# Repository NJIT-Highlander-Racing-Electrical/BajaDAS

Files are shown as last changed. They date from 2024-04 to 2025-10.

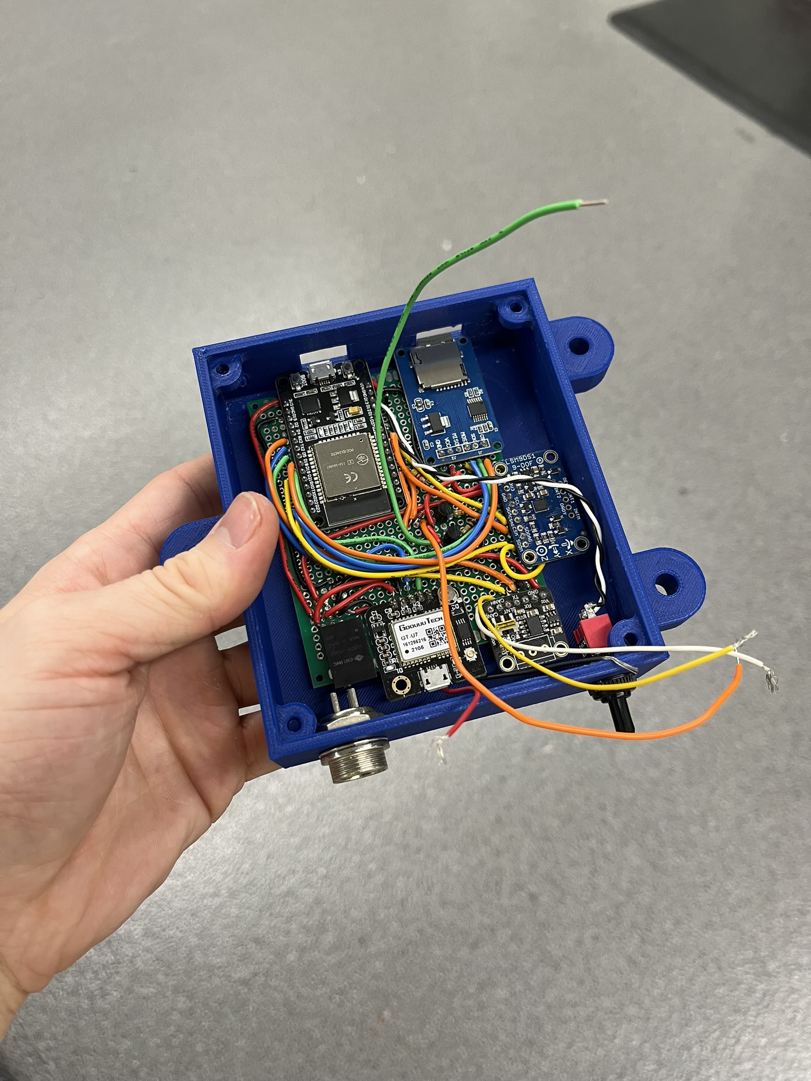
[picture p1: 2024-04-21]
Photos/IMG_1275.JPEG

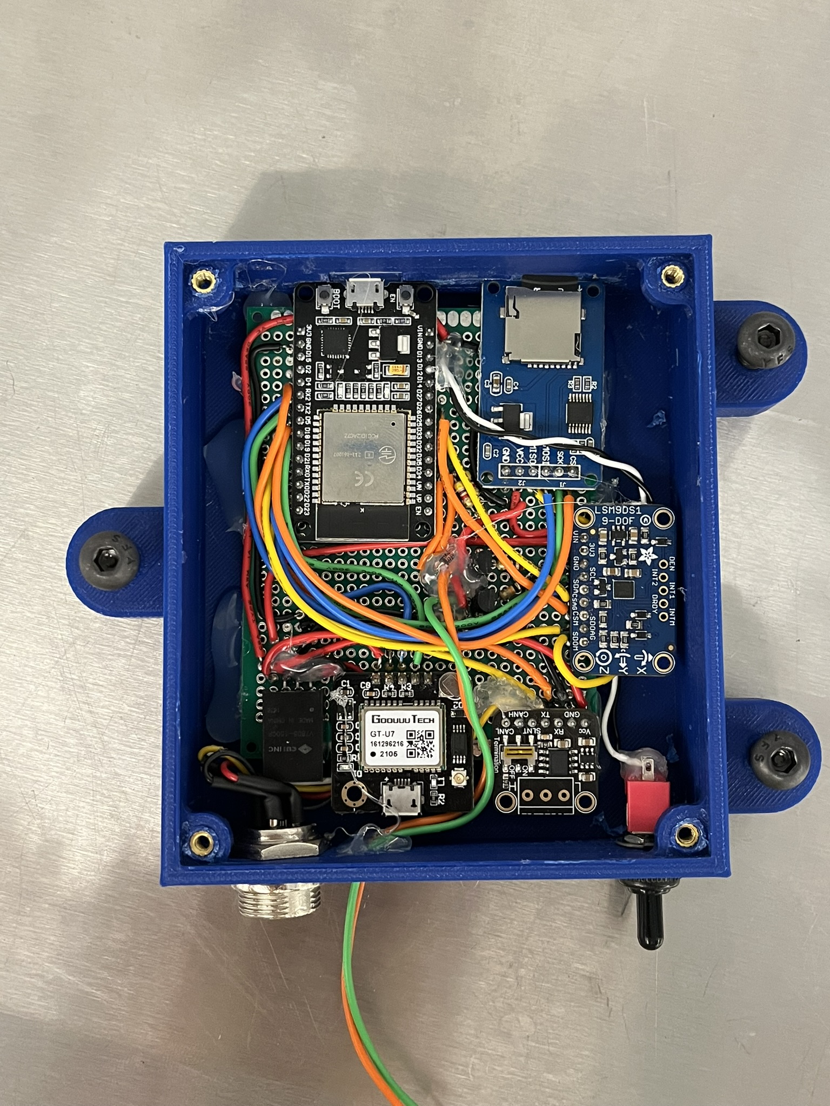
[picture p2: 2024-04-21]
Photos/IMG_1279.JPEG

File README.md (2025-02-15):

# BajaDAS: Readme and Quickstart Guide

## PlatformIO 

1. Install `Visual Studio Code`.
2. Install the `PlatformIO IDE` and `GitHub Repositories` extensions.
3. From a new window, click on `Clone Git Repository` and follow prompts to download a local copy of the code.

## Quick Start

1. Insert a formatted `MicroSD` card into the BajaDAS system.
2. Open the project folder in `Visual Studio Code`.
3. Use the `PlatformIO: Upload` button to load the code onto the microcontroller.
4. Post-race, retrieve the SD card and access the `.csv` files for analysis.

## Troubleshooting

- The main config file is `platformio.ini`.

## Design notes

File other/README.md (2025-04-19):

# BajaDAS: Data Acquisition System for Highlander Racing

BajaDAS is a data acquisition system tailored for the Highlander Racing team's vehicles. It gathers real-time telemetry data, crucial for performance analytics and diagnostics.

## 2025-2026 Changes to Make

* Incorporate this [Adafruit Panel Mount Micro SD Card Extender](https://www.google.com/aclk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) for easier use. This will require a waterproof screw on or press fit cover but will make removing the microSD far easier
     * I think we can also just place a microSD card slot for the other end of that panel mount directly to the PCB. It looks like the "reader" we use now just does some voltage regulation and level shifting, but since the ESP32 already uses 3.3V we may be OK without the additional hardware
     * Update the 3D Model and the PCB accordingly for these changes

* Include external pull-up resistors for any input pins on 34, 35, 36, or 39 since these do not have internal pullups

## Features

- **9-DOF Sensor**: Gathers acceleration, magnetic field, gyroscope, and temperature data via the `Adafruit_LSM9DS1` sensor.
- **GPS Integration**: Records GPS data, specifically latitude, longitude, fix status, and satellite count.
- **SD Card Logging**: Logs data to an SD card in CSV format.
- **Serial Logging**: Outputs sensor readings to the serial console for live monitoring.
- **CAN Bus Support**: Receives all incoming vehicle data using a TJA1051T CAN Transceiver.
- **Connection Modularity**: Screw Terminals on DAQ PCB so that additional modules can be connected to the microcontroller in the future
- **Fuel Sensor**: Integrates the fuel sensor and data storage as a part of the DAS

## Hardware Setup

- **Microcontroller**: Designed for Arduino-compatible boards with multiple hardware serial interfaces and SPI capabilities.
- **SD Card**: MicroSD card slot for data logging. Ensure it's formatted correctly.
- **Sensors**: Adafruit LSM9DS1 9-DOF sensor and a GPS module.

## GPS Information

* GPS System that tracks vehicle location (latitude and longitude) as well as reporting other information like time and date

### GPS Design Goals

* CAN-Bus integration with Adafruit Ultimate GPS module reports latitude, longitude, time, and date
* Active antenna mounted to firewall increases reception

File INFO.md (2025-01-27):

# BajaDAS: Data Acquisition System for Highlander Racing

BajaDAS is a data acquisition system tailored for the Highlander Racing team's vehicles. It gathers real-time telemetry data, crucial for performance analytics and diagnostics.

## King Andrew's Winter Break Updates

* I had some issues with the SD card where I would get the message that "The physical drive cannot work." It turned out to be a bad reader.
  
* Pins 34, 35, 36, 39 do not have internal pullups but we have buttons attahed to 34 and 35. Since buying a whole new PCB for such a minor issue is a royal PITA, I soldered two pullup resistors on the underside of the PCB on the ESP32 from 3.3V to 34 and 35

* The Ultimate GPS Module was not communicating properly with the ESP32 over Hardware Serial 2
    * Originally, I thought this was because the module was given 5V on VIN and was not operating at the proper logic level.
    * However, I found that it does work at either voltage due to the following:
        *  Adafruit says the GPS TX pin is 3.3V logic level (seemingly regardless of VIN voltage)
        *  On GPS RX, "You can use use 3.3V or 5V logic, there is a logic level shifter."
    * I was able to get communication working by reading the data directly to serial without adafruit's parsing stuff: Serial2.begin(9600, SERIAL_8N1, 16, 17);
    * It seems that the Adafruit code does not properly initialize the Serial2 port for reading data
    * The AdafruitGPSTestSketch uplaoded in this repo works to receive and parse data and is a good starting point for the full DAS program

## Important Notes + 2025 Research Topics

* It would be beneficial to add code to offset the "zero" point of the accelerometer/correct the readings. It is not mounted perfectly square on the car relative to ground. This code could also correct gyro readings based off of accelerometer orientation

* Occassionaly, numbers will get shifted or have other erroneous digits added to them in the SD logging. Maybe a buffer should be added that saves every value to that so that no values are misprinted to the log.

* Make sure that the DAS this year saves more of the GPS data. Heading, velocity, elevation, etc

* Make sure that the DAS uses the voltage divider onboard for battery level measurement
    * This will have to be calibrated manually by measuring battery voltage

* Make sure that the GPS is reporting new data at a 10Hz rate

* Make sure DAS transmits vehicle velocity to CAN Bus (for wheel speed sensors slip/skid detection)

* Also make it very easy to switch timezone offsets for GPS time (we'll be in Arizona)

## 2025-2026 Changes to Make

* Incorporate this [Adafruit Panel Mount Micro SD Card Extender](https://www.google.com/aclk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) for easier use. This will require a waterproof screw on or press fit cover but will make removing the microSD far easier
     * I think we can also just place a microSD card slot for the other end of that panel mount directly to the PCB. It looks like the "reader" we use now just does some voltage regulation and level shifting, but since the ESP32 already uses 3.3V we may be OK without the additional hardware
     * Update the 3D Model and the PCB accordingly for these changes

* Include external pull-up resistors for any input pins on 34, 35, 36, or 39 since these do not have internal pullups

## Features

- **9-DOF Sensor**: Gathers acceleration, magnetic field, gyroscope, and temperature data via the `Adafruit_LSM9DS1` sensor.
- **GPS Integration**: Records GPS data, specifically latitude, longitude, fix status, and satellite count.
- **SD Card Logging**: Logs data to an SD card in CSV format.
- **Serial Logging**: Outputs sensor readings to the serial console for live monitoring.
- **CAN Bus Support**: Receives all incoming vehicle data using a TJA1051T CAN Transceiver.
- **Connection Modularity**: Screw Terminals on DAQ PCB so that additional modules can be connected to the microcontroller in the future
- **Fuel Sensor**: Integrates the fuel sensor and data storage as a part of the DAS

## Hardware Setup

- **Microcontroller**: Designed for Arduino-compatible boards with multiple hardware serial interfaces and SPI capabilities.
- **SD Card**: MicroSD card slot for data logging. Ensure it's formatted correctly.
- **Sensors**: Adafruit LSM9DS1 9-DOF sensor and a GPS module.

## GPS Information

* GPS System that tracks vehicle location (latitude and longitude) as well as reporting other information like time and date

### GPS Design Goals

* CAN-Bus integration with Adafruit Ultimate GPS module reports latitude, longitude, time, and date
* Active antenna mounted to firewall increases reception 
  
## Fuel Sensor

* The fuel sensor is integrated into the DAS for the following reasons:
     * It is physically close to the DAS and a simple circuit with few wires
     * It does not require complex math or data processing
     * A fuel reset switch can be embedded into the DAS enclosure
     * There also needs to be a DAQ recording on/off switch
     * The SD Card on the DAS can also include a file with the last known fuel level for when the vehicle is powered back on 

## Quick Start

Note: PlatformIO is required for this project.

1. Open the project files in PlatformIO.
2. Insert a formatted MicroSD card into the BajaDAS system.
3. Use the `PlatformIO: Upload` button to load the code onto the microcontroller.
4. Use a Serial Monitor at a `115200` baud rate to view data.
5. Post-race, retrieve the SD card and access the `.csv` files for analysis.

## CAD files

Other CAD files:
3D Models/DAQ Housing.step
other/3D Models/2024-2025 DAS Enclosure v45.step
2023-2024 Archive/3D Models/DAQ Housing.step

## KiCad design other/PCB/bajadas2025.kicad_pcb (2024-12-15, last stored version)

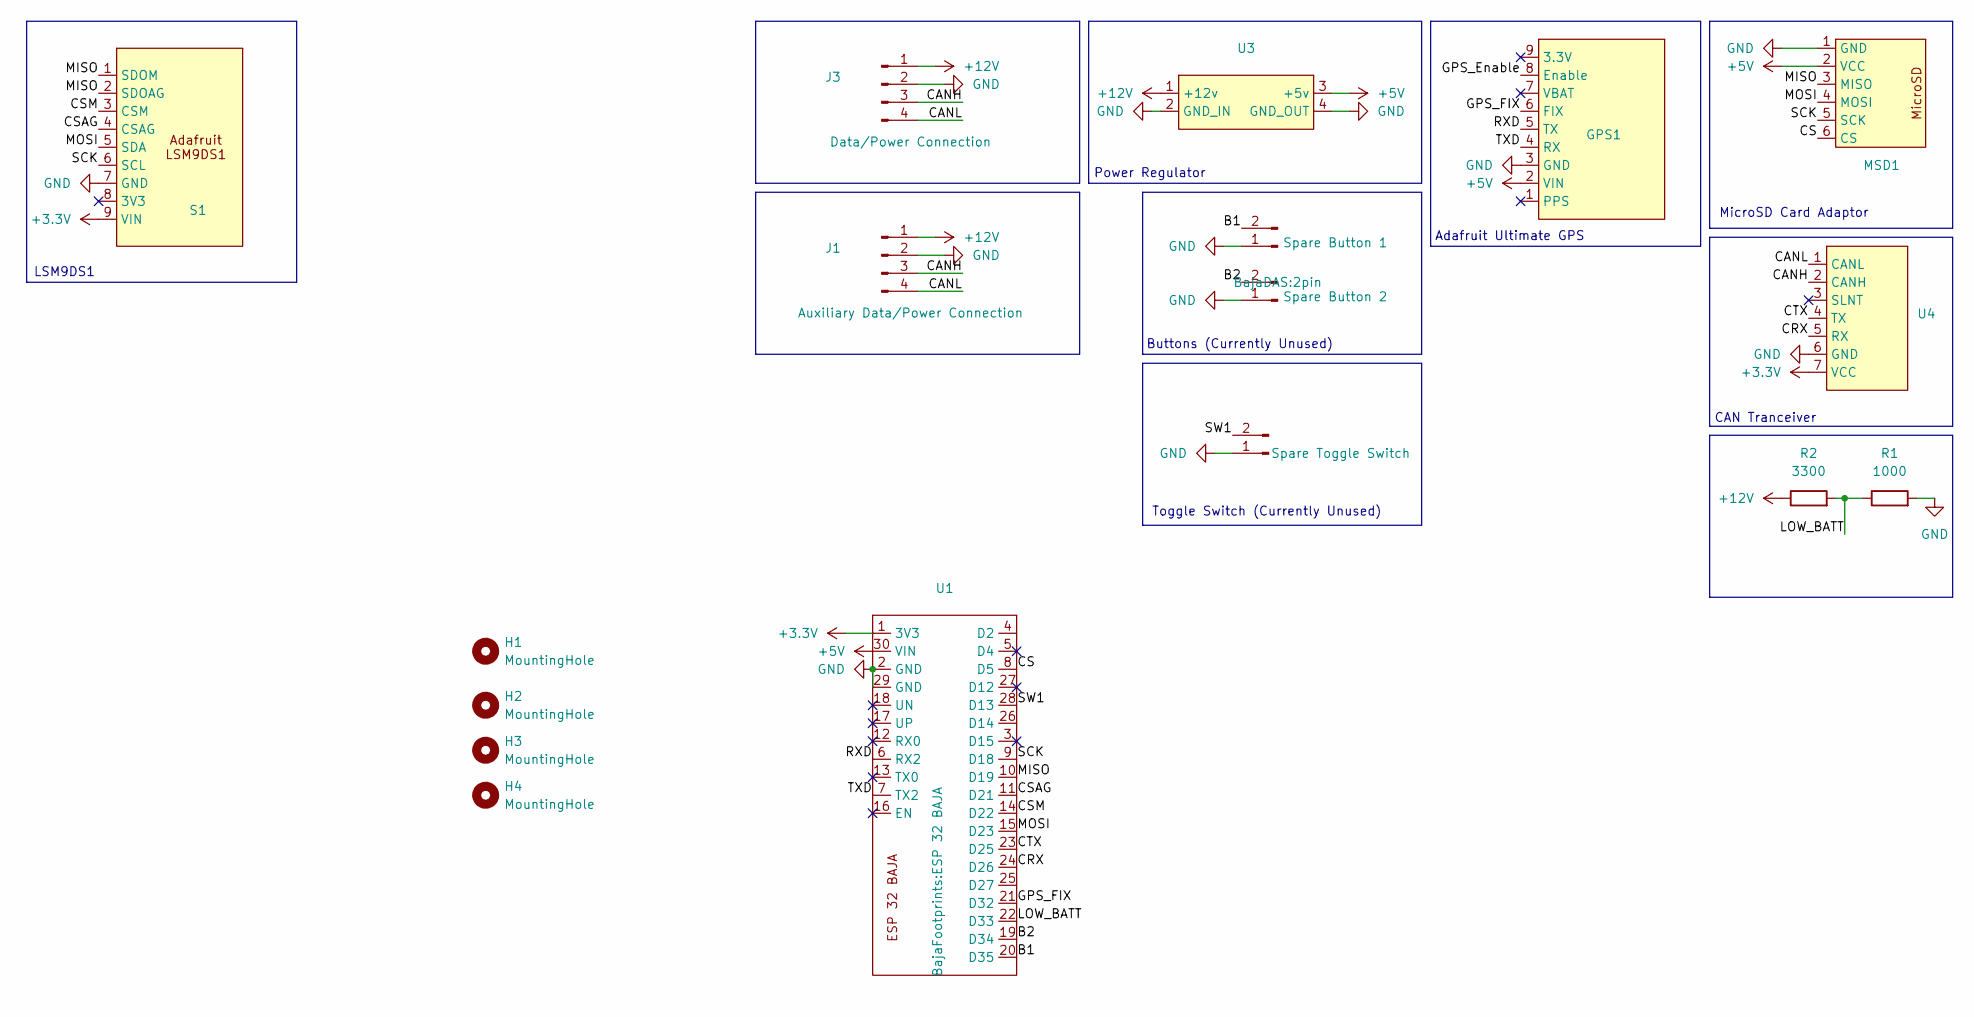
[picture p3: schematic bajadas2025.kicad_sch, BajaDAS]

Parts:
GPS1: Adafruit Ultimate GPS v1
H1, H2, H3, H4: MountingHole; MountingHole_4.3mm_M4
J1: Auxiliary Data/Power Connection; 4pin
J2: Spare Button 1; 2pin
J3: Data/Power Connection; 4pin
J4: Spare Button 2; 2pin
J5: Spare Toggle Switch; 2pin
MSD1: SD Card Reader v1
R1: 1000; R_Axial_DIN0207_L6.3mm_D2.5mm_P10.16mm_Horizontal
R2: 3300; R_Axial_DIN0207_L6.3mm_D2.5mm_P10.16mm_Horizontal
S1: Adafruit LSM9DS1
U1: ESP 32 BAJA
U3: Regulator_v1
U4: CAN Bus Tranceiver v1

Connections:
+3.3V: S1.9 (VIN), U1.1 (3V3), U4.7 (VCC)
+5V: GPS1.2 (VIN), MSD1.2 (VCC), U1.30 (VIN), U3.3 (+5v)
+12V: J1.1, J3.1, R2.1, U3.1 (+12v)
/B1: J2.2, U1.20 (D35)
/B2: J4.2, U1.19 (D34)
/CANH: J1.3, J3.3, U4.2 (CANH)
/CANL: J1.4, J3.4, U4.1 (CANL)
/CRX: U1.24 (D26), U4.5 (RX)
/CS: MSD1.6 (CS), U1.8 (D5)
/CSAG: S1.4 (CSAG), U1.11 (D21)
/CSM: S1.3 (CSM), U1.14 (D22)
/CTX: U1.23 (D25), U4.4 (TX)
/GPS_Enable: GPS1.8 (Enable)
/GPS_FIX: GPS1.6 (FIX), U1.21 (D32)
/LOW_BATT: R1.1, R2.2, U1.22 (D33)
/MISO: MSD1.3 (MISO), S1.1 (SDOM), S1.2 (SDOAG), U1.10 (D19)
/MOSI: MSD1.4 (MOSI), S1.5 (SDA), U1.15 (D23)
/RXD: GPS1.5 (TX), U1.6 (RX2)
/SCK: MSD1.5 (SCK), S1.6 (SCL), U1.9 (D18)
/SW1: J5.2, U1.28 (D13)
/TXD: GPS1.4 (RX), U1.7 (TX2)
GND: GPS1.3 (GND), J1.2, J2.1, J3.2, J4.1, J5.1, MSD1.1 (GND), R1.2, S1.7 (GND), U1.2 (GND), U1.29 (GND), U3.2 (GND_IN), U3.4 (GND_OUT), U4.6 (GND)

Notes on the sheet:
Buttons (Currently Unused)
CAN Tranceiver
Toggle Switch (Currently Unused)
Adafruit Ultimate GPS
Power Regulator
LSM9DS1
MicroSD Card Adaptor

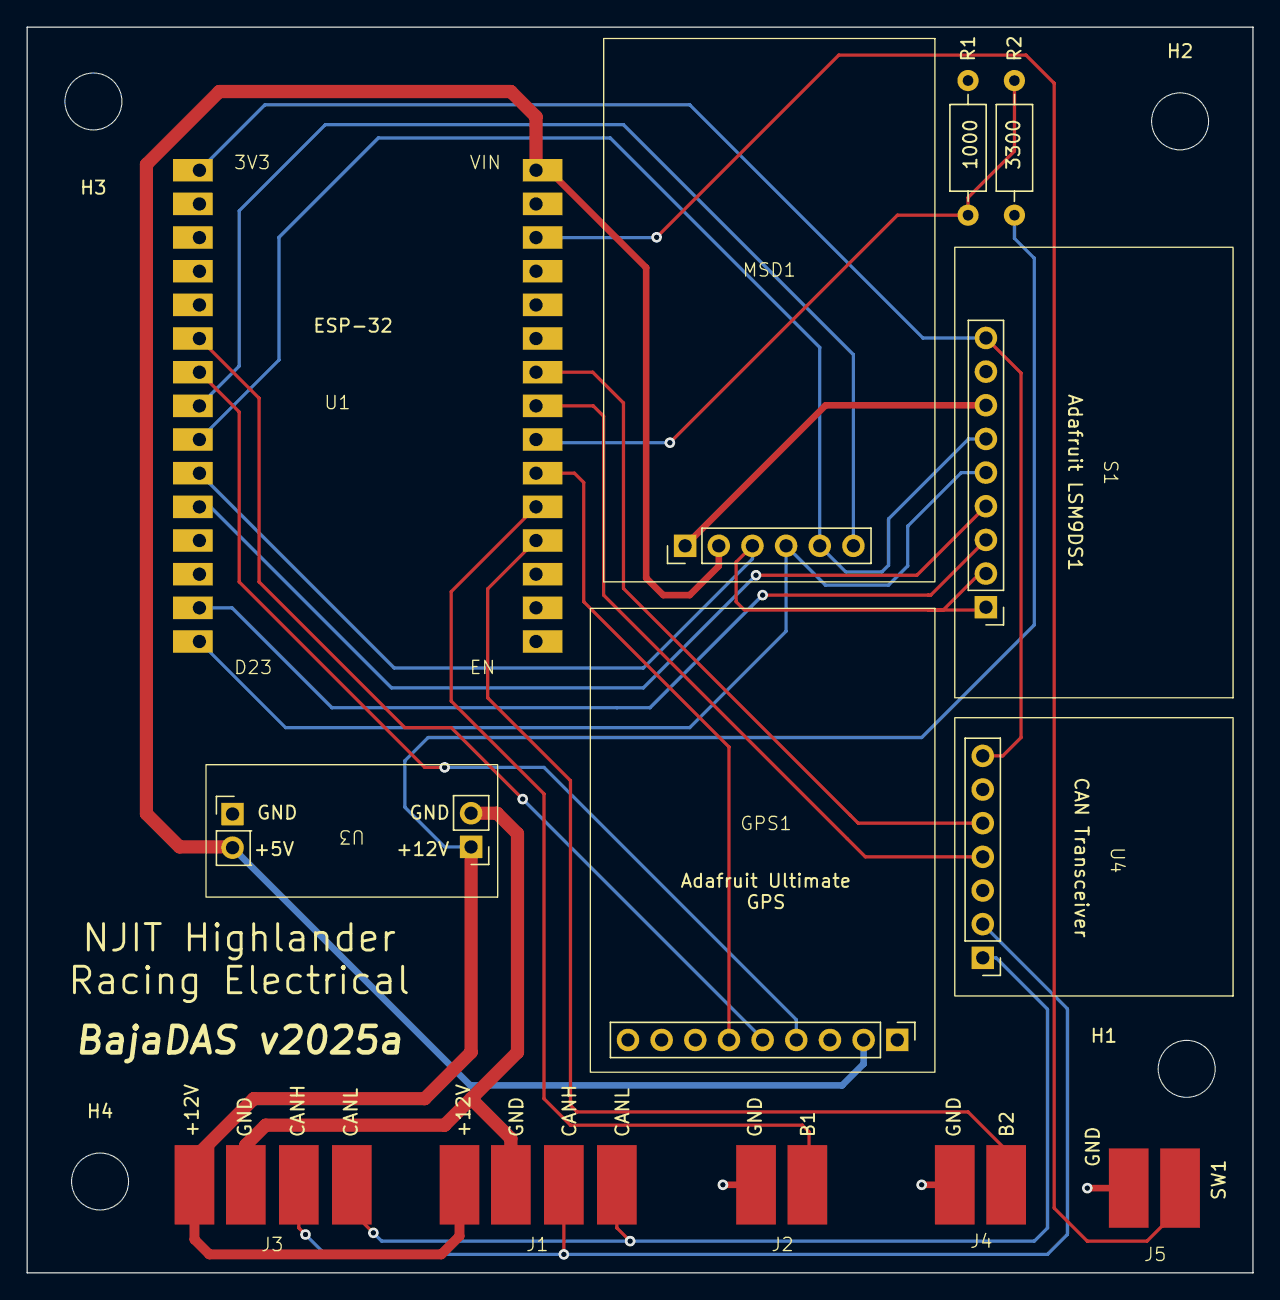
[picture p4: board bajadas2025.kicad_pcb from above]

Board: 2 copper layers, 92.5 x 94.0 mm, 17 parts (0 on the bottom side), 21 nets.

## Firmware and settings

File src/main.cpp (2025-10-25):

// NJIT Highlander Racing - Electrical Subteam

// BajaDAS 2025
// Alexander Huegler

#define TX_GPIO_NUM 25 // Connects to CTX
#define RX_GPIO_NUM 26 // Connects to CRX

bool serialStudioLogging = true; // Set to true if using SerialStudio, false if just using Serial Monitor

#include <math.h>
#include <string>
#include <iostream>
#include <Arduino.h>
#include <Wire.h>
#include "FS.h"
#include "SD.h"
#include <SPI.h>
#include <Adafruit_LSM9DS1.h>
#include <HardwareSerial.h>
#include <BajaCAN.h>

// GPS Date/Time strings
String hourString = "";
String minuteString = "";
String secondString = "";

String dayString = "";
String monthString = "";
String yearString = "";

const int timeZoneOffset = -4; // -5 for EST, -4 for EDT, -7 for Marana, AZ

// buttons & switches
const int buttonPin1 = 35;
const int buttonPin2 = 34;
const int switchPin = 13;

bool dasError = false;

// battery variables
int batteryPin = 33;
float batVoltageDividerRatio = 0.23255813953;
float batteryVoltage;
unsigned long lastBatteryCheckMillis = 0;
int batteryCheckFrequency = 10000; // Check battery voltage once every 10 seconds

// time from program start in seconds
float time_from_start;

// UTC time of gps observation (hours/minutes/seconds.decimal-seconds)
String timedat = "init";

// Chip selects for LSM9DS1
const int8_t XG_CS = 21;
const int8_t M_CS = 22;

// Chip select pin for MicroSD reader
const uint8_t SDCARD_CS = 5;

// GPS initialization variables
String latitude, longitude;
String latitudeDecimal, longitudeDecimal;
String gpsStatus;
HardwareSerial GPS_Serial(2);
bool hasFix = false;
int sats = 0;

// LSM9DS1 variables
Adafruit_LSM9DS1 lsm = Adafruit_LSM9DS1(XG_CS, M_CS);
sensors_event_t a, m, g, temp;

// log file setup
File logFile; // Keep file handle open for fast logging
bool fileCreated = false;           // This variable is used to know if we are creating a new file, or just simply logging (in the main loop)
bool filenameIsDescriptive = false; // So we know what type of file we made. We don't want the conditions to change mid-logging and our files to get corrupted
String logFilePathDescriptive = "/yyyy-mm-dd_hh-mm-ss.csv";
char logFilePath[13] = "/log.csv"; // up to "/log9999.csv" and the null terminator.

// Fast SD logging variables
bool logFileIsOpen = false;
unsigned long lastFlush = 0;
const unsigned long FLUSH_INTERVAL = 200; // Flush every 200ms for power-loss protection

// function declarations here:
void setupSD();
void setupLSM();
void setupGPS();
void setupLoggingMode();
void readLSM();
void updateBatteryPercentage();
void readGPS();

void parseGPGGA(String data);
void parseGPRMC(String data);
String convertToDecimalDegrees(const String &coordinate, bool isLatitude);

void logSerial();
void createFileSD();
void openLogFileOnce();
void fastLogSD();

void setNextAvailableFilePath();

void setup()
{

  // Initialize all input pins
  pinMode(buttonPin1, INPUT_PULLUP);
  pinMode(buttonPin2, INPUT_PULLUP);
  pinMode(switchPin, INPUT_PULLUP);
  pinMode(batteryPin, INPUT);

  // start serial
  Serial.begin(460800);
  delay(1000); // I don't think while(!Serial) works on ESP32, so just delay while the serial initializes

  // setup connections to various modules
  setupGPS();
  setupSD();
  setupLSM();

  // setup CAN
  setupCAN(DAS);

  Serial.println("Finishing Setup");
}

void loop()
{
  delay(1);

  time_from_start = millis() / 1000.0;

  // read data from modules
  readLSM();
  readGPS();
  updateBatteryPercentage();

  // log data to serial connection
  logSerial();

  // log data to SD with keep-file-open approach
  if (sdLoggingActive)
  {
    // Open file once and keep it open
    if (!fileCreated)
    {
      createFileSD();
      openLogFileOnce();
      fileCreated = true;
    }
    
    // Fast logging to already-open file
    if (logFileIsOpen)
    {
      fastLogSD();
    }
  }
  else // If we are here, our logging ended and we should close the file and reset flags
  {
    // Close file when logging stops
    if (logFileIsOpen)
    {
      logFile.close();
      logFileIsOpen = false;
    }
    fileCreated = false;
  }
}

// function definitions here:

void setupLSM()
{
  Serial.print("Initializing LSM9DS1... ");
  if (!lsm.begin())
  {
    Serial.println("Oops ... unable to initialize the LSM9DS1.");
    while (!lsm.begin())
      ;
  }
  Serial.println("Found LSM9DS1 9DOF");

  // 1.) Set the accelerometer range
  // lsm.setupAccel(lsm.LSM9DS1_ACCELRANGE_2G);
  //lsm.setupAccel(lsm.LSM9DS1_ACCELRANGE_4G);
  // lsm.setupAccel(lsm.LSM9DS1_ACCELRANGE_8G);
  lsm.setupAccel(lsm.LSM9DS1_ACCELRANGE_16G);

  // 2.) Set the magnetometer sensitivity
  lsm.setupMag(lsm.LSM9DS1_MAGGAIN_4GAUSS);
  // lsm.setupMag(lsm.LSM9DS1_MAGGAIN_8GAUSS);
  // lsm.setupMag(lsm.LSM9DS1_MAGGAIN_12GAUSS);
  // lsm.setupMag(lsm.LSM9DS1_MAGGAIN_16GAUSS);

  // 3.) Setup the gyroscope
  lsm.setupGyro(lsm.LSM9DS1_GYROSCALE_245DPS);
  // lsm.setupGyro(lsm.LSM9DS1_GYROSCALE_500DPS);
  // lsm.setupGyro(lsm.LSM9DS1_GYROSCALE_2000DPS);
}

void setupSD()
{
  Serial.print("Initializing SD card... ");
  if (!SD.begin(SDCARD_CS))
  {
    Serial.println("Oops... unable to initialize the SD card.");
    dasError = true;
    while (!SD.begin(SDCARD_CS))
      ;
  }

  uint8_t cardType = SD.cardType();

  if (cardType == CARD_NONE)
  {
    Serial.println("No SD card attached");
    dasError = true;
    return;
  }

  Serial.print("SD Card Type: ");
  if (cardType == CARD_MMC)
  {
    Serial.println("MMC");
  }
  else if (cardType == CARD_SD)
  {
    Serial.println("SDSC");
  }
  else if (cardType == CARD_SDHC)
  {
    Serial.println("SDHC");
  }
  else
  {
    Serial.println("UNKNOWN");
  }
  uint64_t cardSize = SD.cardSize() / (1024 * 1024);
  Serial.printf("SD Card Size: %lluMB\n", cardSize);
}

void setupGPS() {
  Serial.println("Initializing GPS on Serial2 at 9600 bps");
  GPS_Serial.begin(9600, SERIAL_8N1, 16, 17); // Start at 9600 default
  
  delay(1000); // Give GPS module time to wake up

  // Step 1: Tell GPS to switch to 57600 baud
  GPS_Serial.println("$PMTK251,57600*2C");
  delay(1000); // Wait for GPS to receive and apply change

  // Step 2: Switch Serial to 57600
  GPS_Serial.end();
  delay(100);
  GPS_Serial.begin(57600, SERIAL_8N1, 16, 17);
  Serial.println("Switched to 57600");

  delay(1000); // Wait for GPS to stabilize at new baud

  // Step 3: Send 10Hz update command
  GPS_Serial.println("$PMTK220,100*2F"); // 100 ms = 10 Hz
  delay(100);

  GPS_Serial.println("$PMTK314,0,1,0,1,0,0,0,0,0,0,0,0,0,0,0,0,0,0,0*28");
  delay(100);
}

// Modified createFileSD - just creates the file, doesn't keep it open
void createFileSD()
{
  setNextAvailableFilePath();

  String filePath;
  if (gpsDateDay > 0 && gpsDateDay <= 31 && gpsDateYear != 2080)
  {
    filePath = logFilePathDescriptive;
    filenameIsDescriptive = true;
  }
  else
  {
    filePath = String(logFilePath);
    filenameIsDescriptive = false;
  }
  
  // Create file and write header if new
  File tempFile = SD.open(filePath, FILE_APPEND);
  if (tempFile)
  {
    dasError = false;
    Serial.printf("Created log file: %s\n", filePath.c_str());
    
    // Write CSV header only if file is new (empty)
    if (tempFile.size() == 0)
    {
      if (!tempFile.println("Hour, Minute, Second, time_from_start, screenshot_flag, bat_voltage, bat_percent, accel_x, accel_y, accel_z, gyro_x, gyro_y, gyro_z, lat, lon, has_fix, num_sats, altitude (ft AGL), heading, velocity (mph), primary_rpm, secondary_rpm, primary_temp, secondary_temp, fl_wheelspeed, fr_wheelspeed, rl_wheelspeed, rr_wheelspeed, fl_wheelstate, fr_wheelstate, rl_wheelstate, rr_wheelstate, fl_wheelpos, fr_wheelpos, rl_wheelpos, rr_wheelpos, front_brake_pressure, rear_brake_pressure, gas_pos, belt_temp"))
      {
        Serial.println("Failed to write header");
      }
    }
    
    tempFile.close();
  }
  else
  {
    Serial.printf("Failed to create file: %s\n", filePath.c_str());
    dasError = true;
  }
}

void openLogFileOnce()
{
  if (filenameIsDescriptive)
  {
    logFile = SD.open(logFilePathDescriptive, FILE_APPEND);
  }
  else
  {
    logFile = SD.open(logFilePath, FILE_APPEND);
  }
  
  if (logFile)
  {
    logFileIsOpen = true;
    Serial.println("Log file opened for fast logging");
  }
  else
  {
    Serial.println("Failed to open log file for logging");
    dasError = true;
  }
}
void fastLogSD()
{
  if (!logFile) return;
  
  // Write data - fast operation (~1ms)
  // Format must match logSerial() output exactly
  if (!logFile.printf("%s,%s,%s,%.3f,%i,%.3f,%i,%.3f,%.3f,%.3f,%.3f,%.3f,%.3f,%.6f,%.6f,%i,%i,%i,%i,%i,%i,%i,%i,%i,%i,%.3f,%.3f,%.3f,%.3f,%.3f,%.3f,%.3f,%.3f,%i,%i,%i,%i\n", 
      hourString.c_str(), minuteString.c_str(), secondString.c_str(),  // Time strings
      time_from_start,  // float with 3 decimals
      dataScreenshotFlag,  // int
      batteryVoltage,  // float with 3 decimals
      batteryPercentage,  // int
      a.acceleration.x, a.acceleration.y, a.acceleration.z,  // Accelerometer (3 decimals each)
      g.gyro.x, g.gyro.y, g.gyro.z,  // Gyroscope (3 decimals each)
      gpsLatitude, gpsLongitude,  // GPS position (6 decimals each) - CHANGED from string to float
      hasFix, sats, gpsAltitude, gpsHeading, gpsVelocity,  // GPS data (int)
      primaryRPM, secondaryRPM, primaryTemperature, secondaryTemperature,  // CVT data (int)
      beltTemperature,  // Belt temp (int)
      frontLeftWheelSpeed, frontRightWheelSpeed, rearLeftWheelSpeed, rearRightWheelSpeed,  // Wheel speeds (3 decimals)
      frontLeftDisplacement, frontRightDisplacement, rearLeftDisplacement, rearRightDisplacement,  // Suspension (3 decimals)
      frontBrakePressure, rearBrakePressure, gasPedalPercentage,  // Pedal/brake data (int)
      sdLoggingActive))  // SD logging status (int) - THIS WAS MISSING!
  {
    Serial.println("Fast logging failed");
  }
  
  // Periodic flush for power-loss protection
  unsigned long currentTime = millis();
  if (currentTime - lastFlush >= FLUSH_INTERVAL)
  {
    logFile.flush(); // Force write to SD card
    lastFlush = currentTime;
  }
}

void readLSM()
{
  lsm.read(); /* ask it to read in the data */

  /* Get a new sensor event */
  lsm.getEvent(&a, &m, &g, &temp);

  accelerationX = a.acceleration.x;
  accelerationY = a.acceleration.y;
  accelerationZ = a.acceleration.z;

  gyroscopePitch = g.gyro.x;
  gyroscopeYaw = g.gyro.y;
  gyroscopeRoll = g.gyro.z;
}

void logSerial()
{ // Write all values to the console

  char sepChar; // Separation character, either a comma or a tab

  if (serialStudioLogging)
  {
    sepChar = ','; // Use comma separated variables for serial studio loggin
  }
  else
  {
    sepChar = '\t'; // If we are just using the serial monitor, make it look nice using tabs instead
  }

  // Time data
  Serial.print(hourString);
  Serial.print(sepChar);
  Serial.print(minuteString);
  Serial.print(sepChar);
  Serial.print(secondString);
  Serial.print(sepChar);
  Serial.print(time_from_start, 3); // Assuming time_from_start is program time in seconds. This can be plotted on the x-axis!

  // Data Screenshot Flag Marker
  Serial.print(sepChar);
  Serial.print(dataScreenshotFlag);

  // Battery Data
  Serial.print(sepChar);
  Serial.print(batteryVoltage, 3);
  Serial.print(sepChar);
  Serial.print(batteryPercentage);

  // Accel data
  Serial.print(sepChar);
  Serial.print(a.acceleration.x, 3); // Accel X
  Serial.print(sepChar);  
  Serial.print(a.acceleration.y, 3); // Accel Y
  Serial.print(sepChar);
  Serial.print(a.acceleration.z, 3); // Accel Z

  // Gyro data
  Serial.print(sepChar);
  Serial.print(g.gyro.x, 3); // Gyro X
  Serial.print(sepChar);
  Serial.print(g.gyro.y, 3); // Gyro Y
  Serial.print(sepChar);
  Serial.print(g.gyro.z, 3); // Gyro Z

  // GPS data
  Serial.print(sepChar);
  Serial.print(gpsLatitude, 6); // GPS Latitude (with 6 decimal places)
  Serial.print(sepChar);
  Serial.print(gpsLongitude, 6); // GPS Longitude (with 6 decimal places)
  Serial.print(sepChar);
  Serial.print(hasFix); // GPS Fix
  Serial.print(sepChar);
  Serial.print(sats); // GPS Satellites
  Serial.print(sepChar);
  Serial.print(gpsAltitude); // GPS Altitude
  Serial.print(sepChar);
  Serial.print(gpsHeading); // GPS Heading
  Serial.print(sepChar);
  Serial.print(gpsVelocity); // GPS Velocity

  // CVT Data
  Serial.print(sepChar);
  Serial.print(primaryRPM);
  Serial.print(sepChar);
  Serial.print(secondaryRPM);
  Serial.print(sepChar);
  Serial.print(primaryTemperature);
  Serial.print(sepChar);
  Serial.print(secondaryTemperature);
  Serial.print(sepChar);
  Serial.print(beltTemperature);

  // Wheel RPM Data
  Serial.print(sepChar);
  Serial.print(frontLeftWheelSpeed, 3);
  Serial.print(sepChar);
  Serial.print(frontRightWheelSpeed, 3);
  Serial.print(sepChar);
  Serial.print(rearLeftWheelSpeed, 3);
  Serial.print(sepChar);
  Serial.print(rearRightWheelSpeed, 3);

  // Wheel Displacement Data
  Serial.print(sepChar);
  Serial.print(frontLeftDisplacement, 3);
  Serial.print(sepChar);
  Serial.print(frontRightDisplacement, 3);
  Serial.print(sepChar);
  Serial.print(rearLeftDisplacement, 3);
  Serial.print(sepChar);
  Serial.print(rearRightDisplacement, 3);

  // Pedal Data
  Serial.print(sepChar);
  Serial.print(frontBrakePressure);
  Serial.print(sepChar);
  Serial.print(rearBrakePressure);
  Serial.print(sepChar);
  Serial.print(gasPedalPercentage);

  // SD Logging Active
  Serial.print(sepChar);
  Serial.print(sdLoggingActive);

  Serial.println(); // Finish with a newline
}


void updateBatteryPercentage()
{

  if ((millis() - lastBatteryCheckMillis) > batteryCheckFrequency)
  {

    int numSamples = 10;

    float voltageReadingList[numSamples];

    // take 10 readings for averaging
    for (int i = 0; i < numSamples; i++)
    {
      voltageReadingList[i] = float(analogRead(batteryPin)) / 4095 * 3.3 * 1.025 / batVoltageDividerRatio; // multiplied by 1.025 to account for voltage drop
    }

    // sum up those 10 readings
    float readingsSum = 0;
    for (int i = 0; i < numSamples; i++)
    {
      readingsSum += voltageReadingList[i];
    }

    // calculate average

    batteryVoltage = readingsSum / numSamples;

    if (batteryVoltage >= 12.60)
      batteryPercentage = 100;
    else if (batteryVoltage >= 12.54)
      batteryPercentage = 95;
    else if (batteryVoltage >= 12.48)
      batteryPercentage = 90;
    else if (batteryVoltage >= 12.42)
      batteryPercentage = 85;
    else if (batteryVoltage >= 12.36)
      batteryPercentage = 80;
    else if (batteryVoltage >= 12.30)
      batteryPercentage = 75;
    else if (batteryVoltage >= 12.18)
      batteryPercentage = 70;
    else if (batteryVoltage >= 12.06)
      batteryPercentage = 65;
    else if (batteryVoltage >= 11.94)
      batteryPercentage = 60;
    else if (batteryVoltage >= 11.82)
      batteryPercentage = 55;
    else if (batteryVoltage >= 11.70)
      batteryPercentage = 50;
    else if (batteryVoltage >= 11.58)
      batteryPercentage = 45;
    else if (batteryVoltage >= 11.46)
      batteryPercentage = 40;
    else if (batteryVoltage >= 11.34)
      batteryPercentage = 35;
    else if (batteryVoltage >= 11.22)
      batteryPercentage = 30;
    else if (batteryVoltage >= 11.10)
      batteryPercentage = 25;
    else if (batteryVoltage >= 10.98)
      batteryPercentage = 20;
    else if (batteryVoltage >= 10.86)
      batteryPercentage = 15;
    else if (batteryVoltage >= 10.74)
      batteryPercentage = 10;
    else if (batteryVoltage >= 10.62)
      batteryPercentage = 5;
    else if (batteryVoltage >= 10.50)
      batteryPercentage = 0;
    else
      batteryPercentage = 0; // Below 10.5V is over-discharged

      lastBatteryCheckMillis = millis();

  }
}

void readGPS()
{
  while (GPS_Serial.available())
  {
    String gpsData = GPS_Serial.readStringUntil('\n');  // Read a line of data from the GPS serial port
    gpsData.trim();                                     // Remove any leading or trailing whitespace/newline characters

    if (gpsData.startsWith("$GPGGA"))                   // Check if the line is a GPGGA sentence
    {
      parseGPGGA(gpsData);                              // Parse the GPGGA sentence for position, fix, satellites, altitude, etc.
    }
    else if (gpsData.startsWith("$GPRMC"))              // Check if the line is a GPRMC sentence
    {
      parseGPRMC(gpsData);                              // Parse the GPRMC sentence for speed, heading, date, etc.
    }
  }
}


void setNextAvailableFilePath()
{

  // Check to see if we have a fix for the date. If so, set the log path to the date/time
  if (gpsDateDay > 0 && gpsDateDay <= 31 && gpsDateYear != 2080)
  {
    // If the year is 2080, we appended 2000 to the default 1980 and we should ignore the descriptive file path
    logFilePathDescriptive = "/" + yearString + "-" + monthString + "-" + dayString + "_" + hourString + "-" + minuteString + "-" + secondString + ".csv";
  }

  // If we could not get a date and time, just create a generic log file name (e.g "log4")
  else
  {

    int fileNumber = 0;
    bool fileExists = true;

    while (fileExists)
    {
      // Generate the next file name in the sequence
      snprintf(logFilePath, sizeof(logFilePath), "/log%d.csv", fileNumber);

      // Check if the file exists on the SD card
      fileExists = SD.exists(logFilePath);

      // If the file exists, increment the file number and check again
      if (fileExists)
      {
        fileNumber++;
      }
    }
  }
}

// Function to convert string NMEA data from GPS into usable decimal degrees format
String convertToDecimalDegrees(const String &coordinate, bool isLatitude)
{
  int degreesLength = isLatitude ? 2 : 3; // Determine the number of degrees (DD or DDD)

  // Extract degrees and minutes from the string
  double degrees = coordinate.substring(0, degreesLength).toDouble();
  double minutes = coordinate.substring(degreesLength).toDouble();

  // Convert to decimal degrees
  double decimalDegrees = degrees + (minutes / 60.0);

  // Convert decimal degrees to string
  return String(decimalDegrees, 6); // 6 decimal places
}

// Take the raw gps data and convert - $GPGGA 'Global Positioning System Fix Data'
void parseGPGGA(String data)
{
  if (data.startsWith("$GPGGA"))
  {
    // Split the data using commas
    int maxFields = 15; // GPGGA has a maximum of 15 fields
    String fields[maxFields];
    int fieldCount = 0;

    int start = 0;
    int pos = data.indexOf(',');
    while (pos != -1 && fieldCount < maxFields)
    {
      fields[fieldCount] = data.substring(start, pos);
      fieldCount++;

      start = pos + 1;
      pos = data.indexOf(',', start);
    }
    if (start < data.length() && fieldCount < maxFields)
    {
      fields[fieldCount++] = data.substring(start);
    }

    // Extract time information if available
    if (fieldCount > 0 && fields[1].length() > 0)
    {
      timedat = fields[1];
    }
    else
    {
      timedat = "err";
    }

    hourString = timedat.substring(0, 2);

    int hours = hourString.toInt(); // Convert the string to an integer
    hours += timeZoneOffset;
    // Handle cases where the offset causes the hour to go negative
    if (hours < 0)
    {
      hours += 24; // Wrap around to previous day
    }

    if (hours == 0)
    {
      gpsTimeHour = 12; // Midnight
    }
    else if (hours > 12)
    {
      gpsTimeHour = hours - 12; // Afternoon/evening
    }
    else
    {
      gpsTimeHour = hours; // Morning
    }

    hourString = String(gpsTimeHour);
    if (gpsTimeHour < 10)
    {
      hourString = "0" + hourString;
    }

    minuteString = timedat.substring(2, 4);
    gpsTimeMinute = minuteString.toInt();
    secondString = timedat.substring(4, 6);
    gpsTimeSecond = secondString.toInt();

    // Extract latitude and longitude if available
    if (fieldCount > 4 && fields[2].length() > 0 && fields[4].length() > 0)
    {
      latitude = fields[2];
      longitude = fields[4];
    }
    else
    {
      latitude = "";
      longitude = "";
    }

    // Convert latitude and longitude NMEA strings into decimal degrees strings (for Google Maps, GPS Visualizer, etc)
    if (latitude.length() > 0 && longitude.length() > 0)
    {
      // Convert NMEA coordinates to decimal degrees strings
      latitudeDecimal = convertToDecimalDegrees(latitude, 1);
      gpsLatitude = latitudeDecimal.toFloat();
      longitudeDecimal = "-" + convertToDecimalDegrees(longitude, 0);
      gpsLongitude = longitudeDecimal.toFloat();
    }

    // Extract fix status and satellite count
    if (fieldCount > 6)
    {
      int fix = fields[6].toInt();
      hasFix = (fix > 0);
      sats = fields[7].toInt();
    }
    else
    {
      hasFix = false;
      sats = 0;
    }

    // Extract altitude if available
    if (fieldCount > 9 && fields[9].length() > 0)
    {
      gpsAltitude = fields[9].toFloat(); // Altitude in meters
      gpsAltitude *= 3.28084;            // convert to feet
    }
    else
    {
      gpsAltitude = -1; // Default or error value
    }
  }
}
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

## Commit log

2024-02-17 Minor changes
    -More descriptive comments for how to wire LSM9DS1 to new ESP32 board (devkit v1)
    -Changed failure/success messages in serial monitor to look better (imo)
    -Added a success message for the GPS module
    Coding changes are minor, but a whole new breadboard layout was started.
    [main.cpp]
2024-02-17 Delete main.cpp
    added to wrong place
    [main.cpp]
2024-04-21 Rename DAQ Housing.step to 3D Models/DAQ Housing.step
    [DAQ Housing.step]
2024-05-14 moving 2023-2024 files to archive
    [DAQ Housing.step]
2024-09-30 Fix some transceiver issues
    [main.cpp]
2024-09-30 Uploaded to wrong spot
    [main.cpp]
2024-09-30 Fix some transceiver issues (part 2)
    [main.cpp]
2024-10-06 Update main.cpp to save singular wheel speed sensor data
2024-10-24 Add another %i for SD card logging for wheel speed
2024-11-15 Add first version of DAS enclosure
2024-11-17 Update Enclosure
2024-12-15 Initial PCB Commit
    [bajadas2025.kicad_pcb, bajadas2025.kicad_sch]
2024-12-15 Various Modifications
    Update Data/Power Connection to use pads
    Update spare buttons to use pads
    Update spare buttons to be tied to ground (to use internal pullup)
    Fix Ultimate GPS to use GPS_RX->ESP32_TX and GPS_TX-ESP32_RX
    Connect GPS_FIX to an arbitrary GPIO input pin in case we want to use it in the future
    Add pads for toggle switch
    Add second set of pads for auxiliary aviation plug connector
    Update positioning of components on PCB
    Add voltage divider circuit for measuring battery voltage
    Move CAN-TX and CAN-RX to standardized GPIO
    [bajadas2025.kicad_pcb, bajadas2025.kicad_sch]
2024-12-15 Update 3D Models for new PCB
2025-01-03 Add welding alignment bracket to 3D Model
2025-01-29 Rename "other" folder
    [bajadas2025.kicad_pcb, bajadas2025.kicad_sch]
2025-02-15 Revert "delete old files"
    This reverts commit e5d0144e9f0b5f0a34804afeb63550d6ea13255a.
    [bajadas2025.kicad_pcb, bajadas2025.kicad_sch]
2025-02-15 v2 creation
    Created a new platformio project and set up easier editing of repository
    [bajadas2025.kicad_pcb, bajadas2025.kicad_sch]
2025-02-16 readding misc. files
    [bajadas2025.kicad_pcb, bajadas2025.kicad_sch]
2025-02-22 changed platformio.ini to use correct can branch
    [main.cpp]
2025-04-05 Time now prints with \t instead of colon
    This helps so that when we replace the \t with a , for SerialStudio, the parsing does nto get messed up
    [main.cpp]
2025-04-05 Fix order of message printing for serial studio
    [main.cpp]
2025-04-05 Increase # of decimal places when serial printing GPS
2025-04-05 Update (GPS heading and velocity and altitude stuff)
2025-04-05 Up Serial baud rate to 460800 (so we spend less time processing serial print requests)
2025-04-06 Update GPS to 10Hz rate
2025-04-12 Add code for brake pressure sensors
2025-04-13 Fix date not being parsed in parseGPRMC
    [main.cpp]
2025-04-13 Fix date/month/year strings not being updated for file path descriptive
    [main.cpp]
2025-04-19 Rename other/2024-2025 DAS Enclosure v45.step to other/3D Models/2024-2025 DAS Enclosure v45.step
    [2024-2025 DAS Enclosure v45.step]
2025-04-25 Serial.begin issues again
    It looks like after some short research that while(!Serial) does not work on ESP32's? So just testing to see if a delay is sufficient
    [main.cpp]
2025-05-02 Change wheel speed units from RPM to MPH
2025-05-02 Update wheel rpm to MPH and change units for logging to SD
2025-05-02 Fix bug where date was showing as 2080 in descriptive log file
    [main.cpp]
2025-05-03 Nevermind, hour was hardcoded to -4, fixed that to use timezone offset
    [main.cpp]
2025-05-03 Fix sign of timezone correction
    [main.cpp]
2025-06-12 Fix separation character for serial monitor printing
    [main.cpp]
2025-06-13 Update ranges for wheel speed and battery voltage
2025-06-14 (TESTING FILE) plus fixes
    Added a testing line to see if GPS is actually printing 10 Hz (looks slower in serial studio replay)
    Updated all Serial.prints for SerialStudio and Serial Monitor to only print 3 decimal places. Hopefully this will fix the issue with data shifts in the CSVs (assuming it is coming from printing long floats)
    [main.cpp]
2025-06-14 Delay after baud rate change to maybe fix it
    [main.cpp]
2025-06-14 Successfully fixed GPS not parsing every 100ms (10Hz
    [main.cpp]
2025-06-14 Fix wheel displacement range
2025-09-06 removed extraneous files
    [2024-2025 DAS Enclosure v45.step, bajadas2025.kicad_pcb, bajadas2025.kicad_sch]
2025-09-06 Remove wheel states from SD logging and SerialStudio/Serial Logging
2025-09-06 Fix printing after removing wheel states
2025-09-06 Increase serial print rate to 460800
    this should allow to faster and more prints to serial monitor. also allows for more saves to SD card. That might be our bottleneck for SD logging rate
2025-09-07 Several updates, see desc
    These updates are to increase the max possible polling rate. Claude rewrote code to have faster SD logging (keeps file open and flushes every so often to not lose tons of data on power off). I rewrot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
2025-10-24 Update program to include CVT belt temp
2025-10-24 Update accelerometer to 16g
2025-10-25 Fix printing
2025-10-25 Fix incorrect printing order
    Belt temp was added in two different spots so serial studio printing was not wokring right for SD vs Serial realtime
    [main.cpp]
